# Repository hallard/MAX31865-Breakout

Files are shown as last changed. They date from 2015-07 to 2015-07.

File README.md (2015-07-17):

MAX31865 PT100, PT1000 RTD sensors Breakout board
=================================================

It's not the first time I want to measure sensors but one of the most used in industry are the PT100 and PT1000, and a friend of mine asked me several times to be able to easily measure temperature with these sensors. Here that breakout board

Detailed Description
====================

Everything is documented on this dedicated [post][1]

### Schematic  
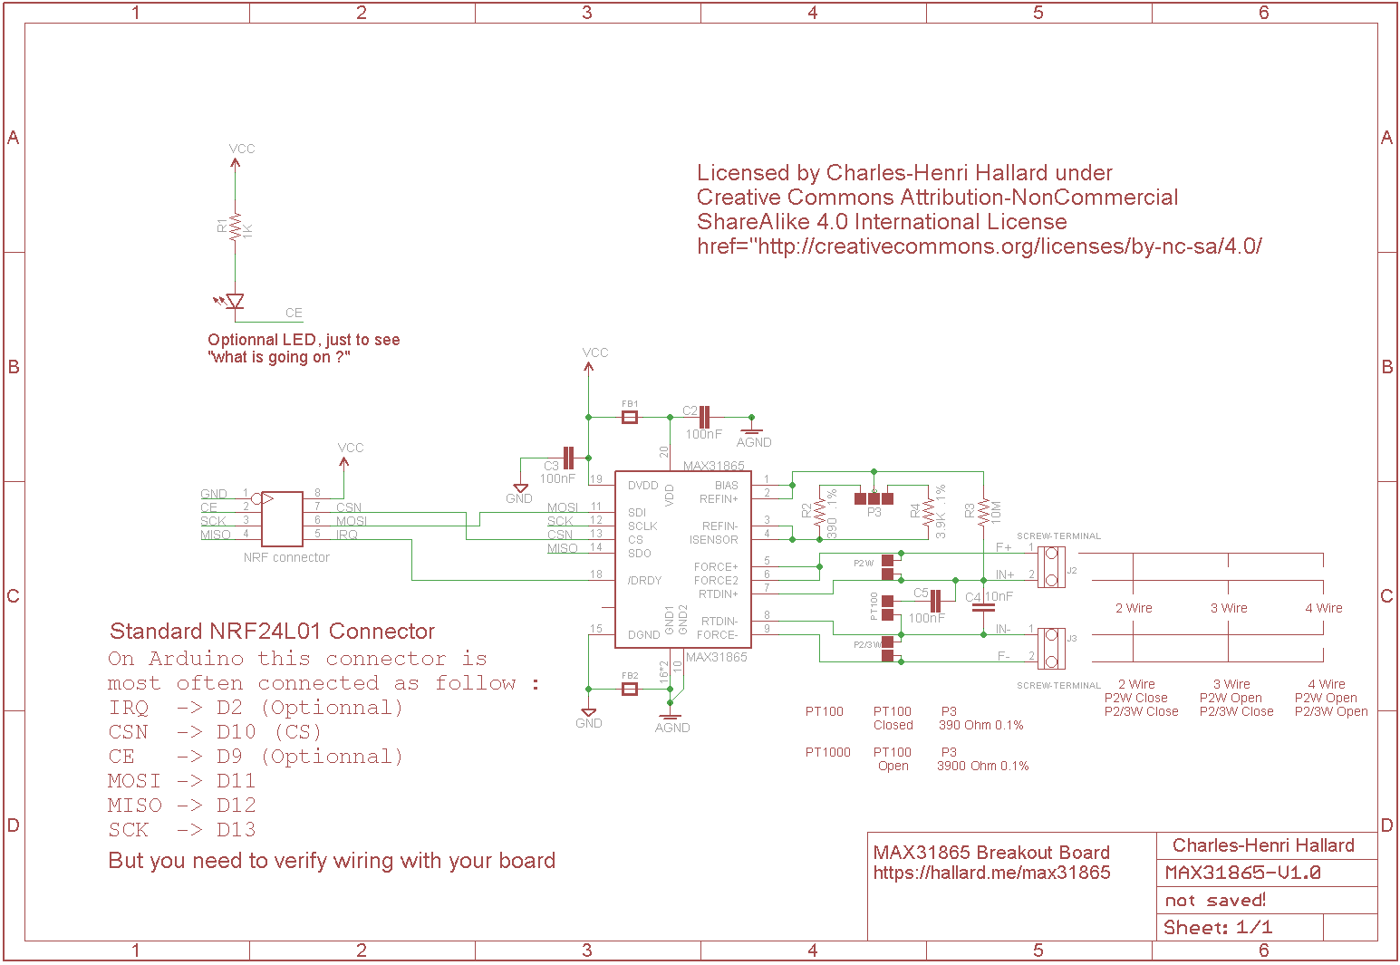
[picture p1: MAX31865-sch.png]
schematic
  

### Boards  
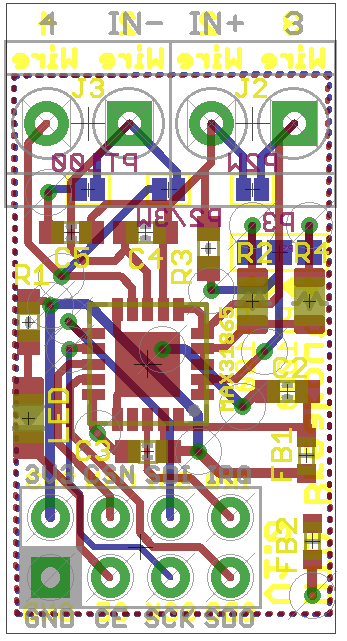
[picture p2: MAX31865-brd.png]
board V1.0
&nbsp;
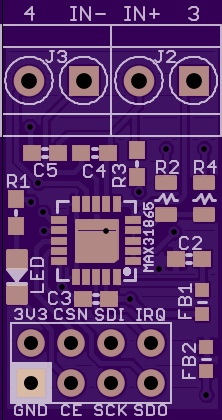
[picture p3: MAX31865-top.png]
top V1.0
&nbsp;
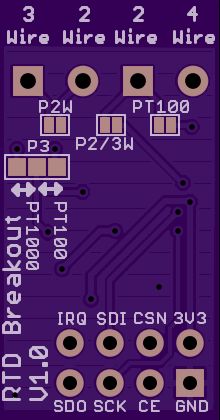
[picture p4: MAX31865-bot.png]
bottom V1.0


##Library
When I created the MAX31865 breakout board, I needed a library to be able to read results. I then found one which was working file. I just added on it some features I needed, thank to Original library author olewolf.
- you can find the forked libray and sample code [here][3]

##Action
When all is fine, display temperature and Resistor value (reference also)    
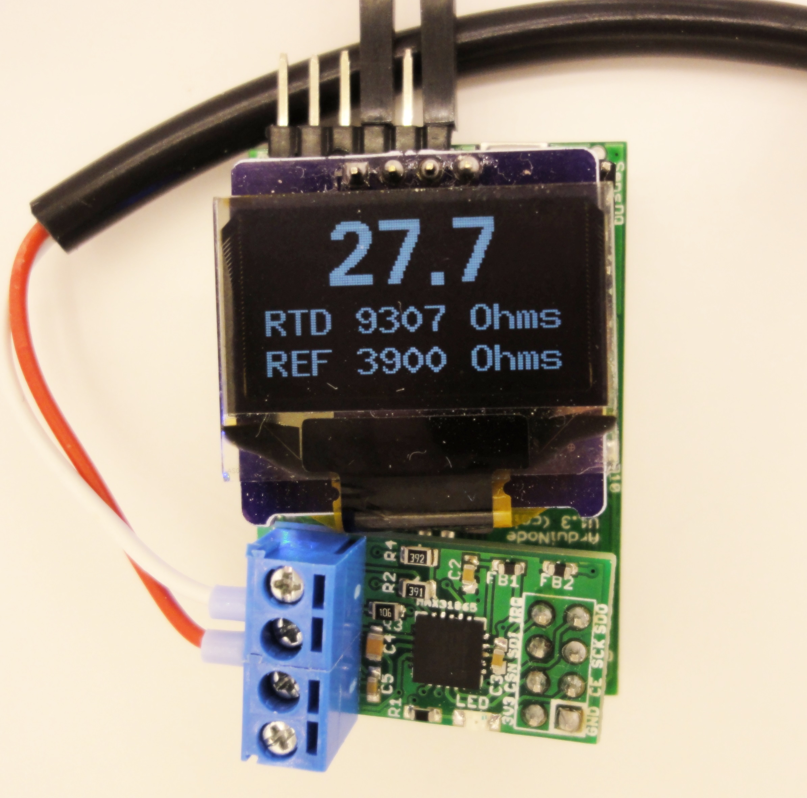
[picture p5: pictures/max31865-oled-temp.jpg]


and when there is a problem such as sensor not connected or breakout board not plugged   
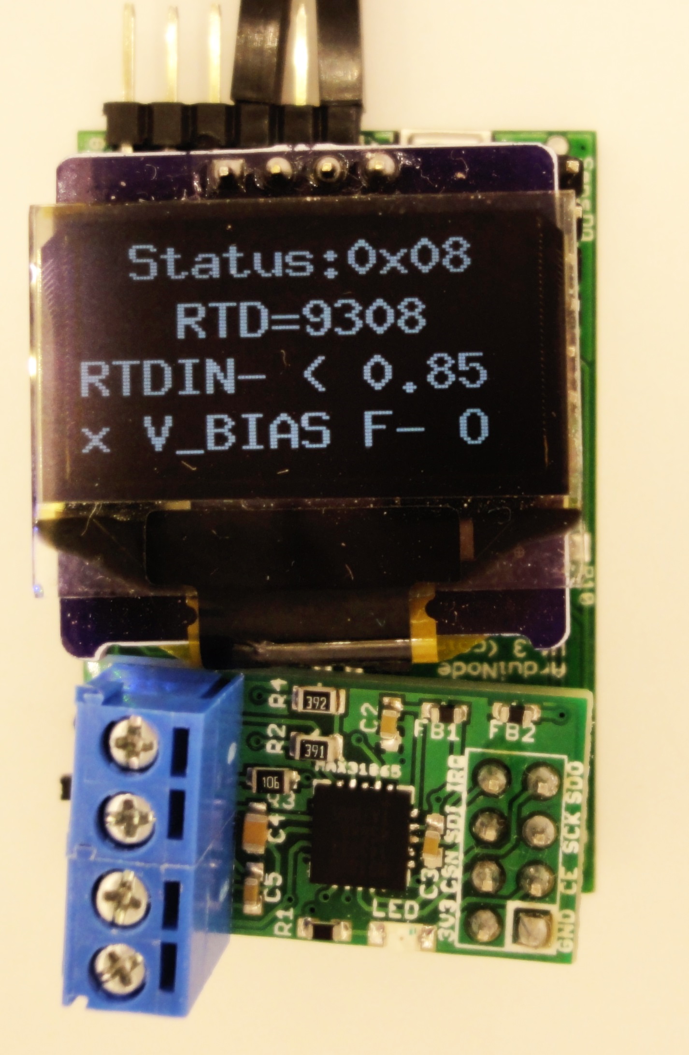
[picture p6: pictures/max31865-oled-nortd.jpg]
No sensor connected
&nbsp;
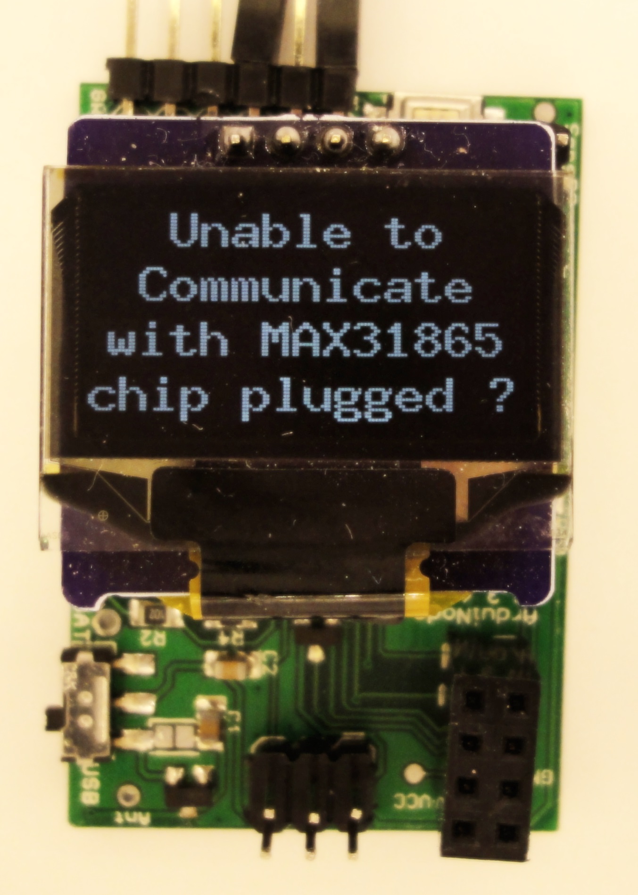
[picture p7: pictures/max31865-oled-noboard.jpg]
No breakout board connected


##License

<br /><span xmlns:dct="http://purl.org/dc/terms/" property="dct:title">MAX31865 PT100, PT1000 RTD Sensors Breakout Board</span> by <a xmlns:cc="http://creativecommons.org/ns#" href="https://hallard.me/max31865" property="cc:attributionName" rel="cc:attributionURL">Charles-Henri Hallard</a> is licensed under a <a rel="license" href="http://creativecommons.org/licenses/by-nc-sa/4.0/">Creative Commons Attribution-NonCommercial-ShareAlike 4.0 International License</a>.<br />Based on a work at <a xmlns:dct="http://purl.org/dc/terms/" href="https://github.com/hallard/MAX31865-Breakout" rel="dct:source">https://github.com/hallard/MAX31865-Breakout</a>.

##Misc
See news and other projects on my [blog][2] 
 
[1]: http://hallard.me/max31865/
[2]: http://hallard.me
[3]: https://github.com/hallard/arduino-max31865/

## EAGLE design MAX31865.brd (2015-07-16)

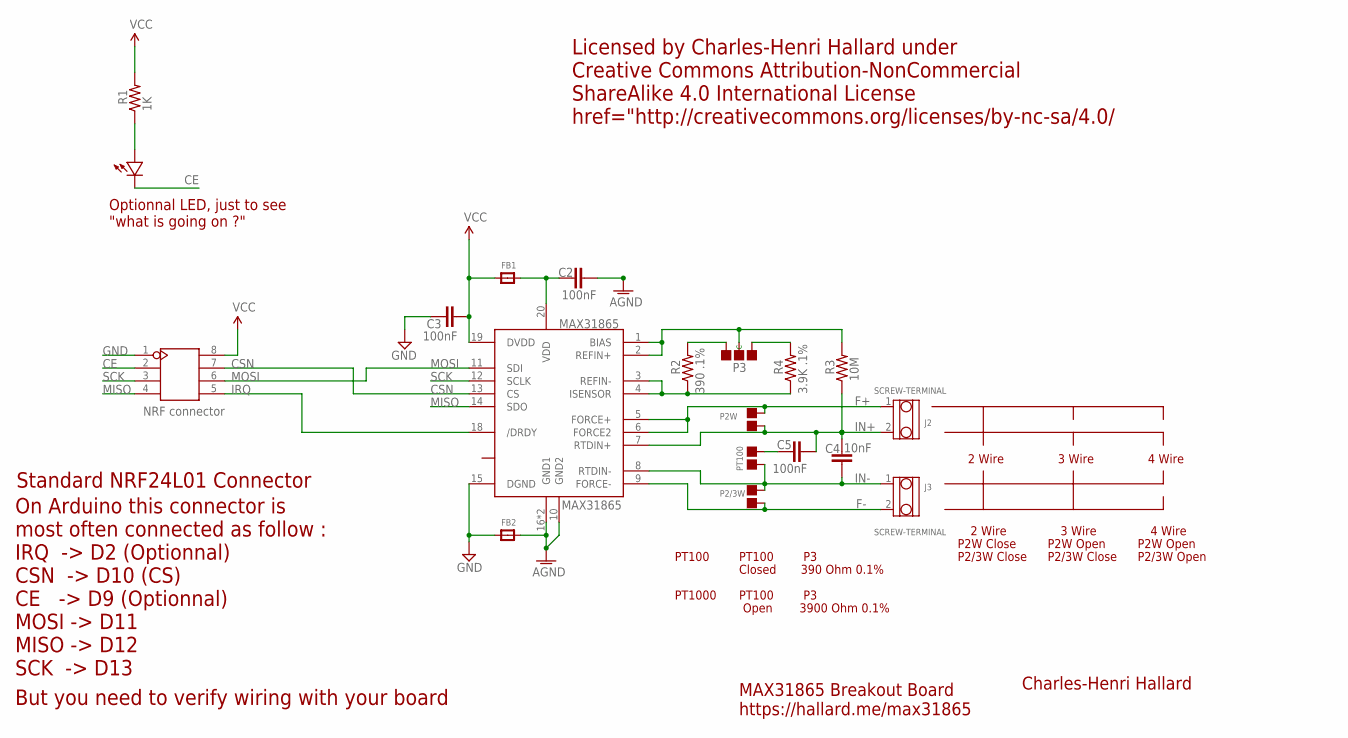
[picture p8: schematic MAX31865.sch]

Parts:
C2, C3, C5: 100nF; 0603-CAP
C4: 10nF; 0603-CAP
FB1, FB2: FERRITE_0603MP; _0603MP
J1: NRF connector; 2X4P-2.54
J2, J3: SCREW-TERMINAL; 2P-3.5
MAX31865: MAX31865; TQFN20-5X5
P2/3W: 4 Wire; 2P-SMD-1.78X1.27
P2W: 3 Wire; 2P-SMD-1.78X1.27
P3: PAD-JUMPER-3P-40*40; 3P-SMD-4.1X1.5
PT100: PAD-JUMPER-2P; 2P-SMD-1.78X1.27
R1: 1K; 0603-RES
R2: 390 .1%; 0805-RES
R3: 10M; 0603-RES
R4: 3.9K .1%; 0805-RES
U$1: LED0805-LARGE; 0805-LED-LARGEPADS

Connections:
AGND: C2.2, FB2.2, MAX31865.10 (GND2), MAX31865.16 (GND1), MAX31865.EXP (GND1)
AVDD: C2.1, FB1.2, MAX31865.20 (VDD)
CE: J1.2, U$1.MINUS
CSN: J1.7, MAX31865.13 (CS)
F+: J2.1, MAX31865.5 (FORCE+), MAX31865.6 (FORCE2), P2W.2
F-: J3.2, MAX31865.9 (FORCE-), P2/3W.1
GND: C3.2, FB2.1, J1.1, MAX31865.15 (DGND)
IN+: C4.1, C5.2, J2.2, MAX31865.7 (RTDIN+), P2W.1, R3.1
IN-: C4.2, J3.1, MAX31865.8 (RTDIN-), P2/3W.2, PT100.1
IRQ: J1.5, MAX31865.18 (/DRDY)
MISO: J1.4, MAX31865.14 (SDO)
MOSI: J1.6, MAX31865.11 (SDI)
unnamed: R1.1, U$1.PLUS
unnamed: P3.11 (R), R2.2
unnamed: MAX31865.3 (REFIN-), MAX31865.4 (ISENSOR), R2.1, R4.1
unnamed: MAX31865.1 (BIAS), MAX31865.2 (REFIN+), P3.MM (C), R3.2
unnamed: P3.00 (L), R4.2
unnamed: C5.1, PT100.2
SCK: J1.3, MAX31865.12 (SCLK)
VCC: C3.1, FB1.1, J1.8, MAX31865.19 (DVDD), R1.2

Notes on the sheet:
MAX31865 Breakout Board https://hallard.me/max31865
Charles-Henri Hallard
Optionnal LED, just to see "what is going on ?"
Standard NRF24L01 Connector
PT100
Closed
390 Ohm 0.1%
PT1000
Open
3900 Ohm 0.1%
2 Wire
P2W Close
P2/3W Close
3 Wire
4 Wire
P2W Open
P2/3W Open
On Arduino this connector is most often connected as follow : IRQ -> D2 (Optionnal) CSN -> D10 (CS) CE -> D9 (Optionnal) MOSI -> D11 MISO -> D12 SCK -> D13
But you need to verify wiring with your board
Licensed by Charles-Henri Hallard under Creative Commons Attribution-NonCommercial ShareAlike 4.0 International License href="http://creativecommons.org/licenses/by-nc-sa/4.0/

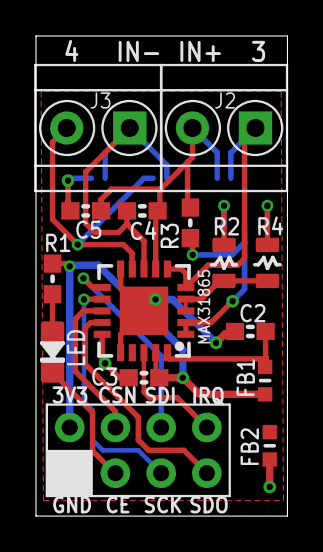
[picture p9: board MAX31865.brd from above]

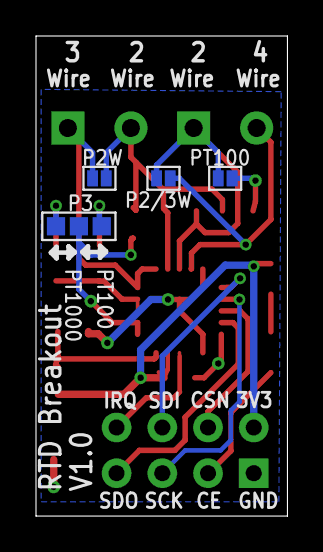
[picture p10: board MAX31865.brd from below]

Board: 2 copper layers, 14.0 x 26.7 mm, 19 parts (4 on the bottom side), 20 nets.

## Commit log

2015-07-16 switched to 600dpi
2016-06-07 Removed version number from filename
    [MAX31865.brd, MAX31865.sch]

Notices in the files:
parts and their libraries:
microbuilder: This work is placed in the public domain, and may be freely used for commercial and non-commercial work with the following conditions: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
